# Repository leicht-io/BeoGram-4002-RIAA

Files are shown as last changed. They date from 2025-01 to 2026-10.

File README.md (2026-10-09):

# BeoGram 4002 RIAA Preamp





An open-source RIAA phono preamplifier board for the Bang & Olufsen **BeoGram 4002 / 4004** turntable, designed in KiCad.

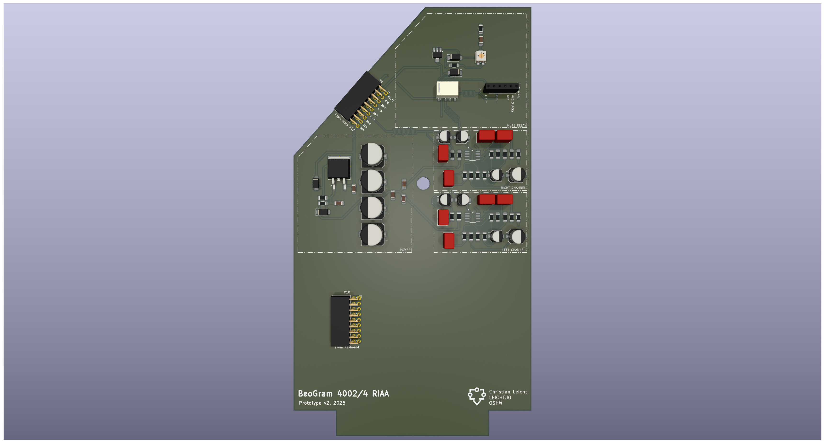
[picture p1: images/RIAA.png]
PCB render


| | |
|---|---|
| **Status** | Prototype v2 (SMD) – manufactured and tested working |
| **Tool** | KiCad 10 (files are readable by KiCad 9) |
| **Board** | 2-layer, 1.6 mm, ~112 × 202 mm |
| **Hardware licence** | [CERN-OHL-S v2](./LICENSE) |
| **Docs licence** | [CC BY-SA 4.0](./LICENSE-DOCS) |

> This project is community driven. Build reports, measurements and design improvements are very welcome – see [CONTRIBUTING.md](./CONTRIBUTING.md).
> Questions and build help: [Discussions](https://github.com/leicht-io/BeoGram-4002-RIAA/discussions).

---

## Contents

- [Technical overview](#technical-overview)
- [Connectors](#connectors)
- [Getting the fabrication files](#getting-the-fabrication-files)
- [Building one](#building-one)
- [Known issues and roadmap](#known-issues-and-roadmap)
- [Repository layout](#repository-layout)
- [Contributing](#contributing)
- [Safety and disclaimer](#safety-and-disclaimer)
- [License](#license)

---

## Technical overview

A dual-stage active/passive RIAA equalizer per channel, based on the classic LM833 application topology but using the **OPA2134** for lower distortion. Full details are in [docs/design-notes.md](./docs/design-notes.md).

- **Stage 1 (U5A / U6A):** non-inverting gain stage that sets the 3180 µs / 318 µs part of the RIAA curve.
- **75 µs network:** passive RC between the stages.
- **Stage 2 (U5B / U6B):** flat gain of about 3.15×.
- **Gain:** about 34 dB at 1 kHz (calculated, not yet measured).
- **Power:** an LM317 makes about 24.6 V from the turntable's 30 V rail. The op-amps run from this single supply, biased at half the supply.
- **Mute relay:** an Omron G6K-2 shorts both outputs to ground until the turntable's `RELAY ON` signal has been present for a while. The delay is set with RV1, and the board mutes instantly when the signal drops.

## Connectors

**P8 – From main PCB** (2×9, 2.54 mm)

| Pin | Signal |
|---|---|
| 1, 2 | RELAY ON |
| 3, 4, 5, 6 | GND |
| 7, 8 | L IN (pickup) |
| 9, 10 | GND |
| 11, 12 | R IN (pickup) |
| 13, 14 | GND |
| 15, 16 | 21 V (relay supply) |
| 17, 18 | 30 V (preamp supply) |

**P10 – From Keyboard** (2×9, 2.54 mm). Power only; the other pins are not connected.

| Pin | Signal |
|---|---|
| 3, 4 | 30 V |
| 11, 12 | 21 V |
| 13, 14 | GND |

**P9 – Output** (1×6, 2.54 mm)

| Pin | Signal |
|---|---|
| 1 | L OUT |
| 3 | R OUT |
| 2, 4, 5, 6 | GND |

## Getting the fabrication files

Gerbers and other fabrication files are **not committed** to the repository. CI generates them from the KiCad sources on every push, so they always match the design:

- **Releases:** every tagged version (`v*`) has a [GitHub release](https://github.com/leicht-io/BeoGram-4002-RIAA/releases) with the gerber zip, a schematic PDF, the BOMs, the pick-and-place file and renders.
- **Latest `main` / any PR:** open the latest [KiCad workflow run](https://github.com/leicht-io/BeoGram-4002-RIAA/actions/workflows/kicad.yml) and download the `fabrication` artifact (you must be logged in to GitHub).
- **Locally:** in KiCad, *File → Fabrication Outputs*, or run the `kicad-cli` commands from [`.github/workflows/kicad.yml`](./.github/workflows/kicad.yml).

The gerbers of the first (v1) prototype are no longer in the tree but remain in the git history.

The CI produces two BOMs:

| File | Contents |
|---|---|
| `RIAA-bom-full.csv` | Every part. The `Assembly` column says whether a part is assembled by JLCPCB or soldered by hand. |
| `RIAA-bom-jlcpcb.csv` + `RIAA-cpl-jlcpcb.csv` | Upload-ready files for JLCPCB SMT assembly. |

## Building one

1. Order the board with SMT assembly using the gerber zip, `RIAA-bom-jlcpcb.csv` and `RIAA-cpl-jlcpcb.csv`. Check the part rotations in JLCPCB's preview before confirming.
2. Hand-solder the parts marked `Hand` in `RIAA-bom-full.csv`: the film capacitors C101–C105 and C201–C205, and C103/C203.
3. Set RV1 for the unmute delay you want.
4. Install it in the turntable. *An illustrated installation guide is still missing – contributions are very welcome.*

Please post a **Build report** issue when you have built one, whether it worked or not.

## Known issues and roadmap

- [ ] **Input load is ~23.5 kΩ, not 47 kΩ.** The cartridge sees the two 47 k bias resistors in parallel. B&O MMC cartridges are specified for 47 kΩ.
- [ ] **All grounds are merged into a single GND net** (chassis, main board, pickup and output). Look at this first if hum shows up.
- [ ] **C104 / C204 (2 µF film) have no part number.**
- [ ] **ERC is not clean:** unused pins need no-connect flags and the supply nets need PWR_FLAGs.
- [ ] **No measurements yet:** RIAA deviation, noise and THD are still missing.
- [ ] **No installation guide or photos yet.**

## Repository layout

```
RIAA.kicad_pro / .kicad_sch / .kicad_pcb   KiCad project
parts/                                     Project-local footprints (OPA2134 D8)
3d-parts/                                  STL files for the 3D-printed board guides
docs/                                      Design notes
images/                                    Renders and photos
scripts/make_bom.py                        Builds the full and JLCPCB BOMs (used by CI)
.github/                                   CI workflow, issue and PR templates
```

## Contributing

See [CONTRIBUTING.md](./CONTRIBUTING.md). In short: open an issue or discussion first for design changes, keep each PR focused, and include screenshots of what you changed in the schematic or PCB.

## Safety and disclaimer

This board connects to the turntable's internal 30 V supply. Vintage equipment can be damaged by wiring mistakes. Everything here is provided **as is, without any warranty** (see the licence), and you build and install it at your own risk.

Bang & Olufsen, BeoGram and related names are trademarks of their owners. This project is not affiliated with or endorsed by Bang & Olufsen.

## License

- **Hardware design files** (KiCad, STL): [CERN Open Hardware Licence v2 – Strongly Reciprocal](./LICENSE) (CERN-OHL-S-2.0)
- **Documentation and images:** [Creative Commons Attribution-ShareAlike 4.0](./LICENSE-DOCS) (CC-BY-SA-4.0)
- **Scripts** (`scripts/`): GPL-3.0-or-later

## Author

Christian Leicht – [leicht.io](https://github.com/leicht-io)

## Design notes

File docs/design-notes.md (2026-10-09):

# Design notes

Theory of operation for the BeoGram 4002 RIAA board. References are for the left channel (1xx). The right channel is the same with 2xx references. All figures are calculated from the schematic values and have **not been measured yet**. Measurements are very welcome.

## Signal path

```
P8 L IN ─ C101 100p ─┬─ C106 10µ ─► U5A (stage 1: 3180/318 µs) ─► R107/R108/C105 (75 µs) ─ C104 2µ ─► U5B (flat ×3.15) ─ C107 10µ ─► K1 (mute) ─► P9 L OUT
                     │              bias: R102/R103 47k/47k to ½ supply
```

### Input

- C101 (100 pF) to ground sets the cartridge capacitive load. Cable capacitance adds to this.
- C106 (10 µF) is the AC coupling cap. The + input is biased at half the supply by R102/R103 (47 k / 47 k).
- **Resistive load:** R102 ∥ R103 ≈ **23.5 kΩ**. The usual moving-magnet / moving-iron load is 47 kΩ, so this is an open point (see the README's known issues).
- **Input high-pass corner:** 10 µF with 23.5 kΩ gives ≈ 0.7 Hz.

### Stage 1 – U5A (3180 µs / 318 µs)

Non-inverting amplifier with feedback Z = R106 + (R105 ∥ C102) to an AC ground through R104 + C103.

| Parameter | Formula | Value | RIAA target |
|---|---|---|---|
| Pole (bass turnover) | R105 · C102 = 80.6 k · 39 n | 3143 µs | 3180 µs |
| Zero | R105·C102 · (R104+R106)/(R104+R105+R106) | ≈ 314 µs | 318 µs |
| Mid-band gain | 1 + R106/R104 | ≈ 17.9 (25 dB) | – |
| LF gain (below 50 Hz) | 1 + (R105+R106)/R104 | ≈ 179 (45 dB) | – |
| DC gain | C103 blocks DC | 1 | – |
| LF corner | R104 · C103 = 499 · 200 µ | ≈ 1.6 Hz | – |

### 75 µs network

- R107 (2.37 k) in series, R108 (54.9 k) to ground, then C105 (33 nF) to ground at the stage 2 input. C104 (2 µF) couples the signal across, since stage 2 has its own half-supply bias (R111/R112).
- **Time constant:** (R107 ∥ R108) · C105 = 2.27 k · 33 n = **75.0 µs**.
- **Flat-band loss:** R108 / (R107 + R108) ≈ 0.96.

### Stage 2 – U5B

- **Gain:** 1 + R109/R110 = 1 + 4.3 k / 2 k ≈ 3.15 (10 dB). C108 (10 µF) makes it unity gain at DC.
- **Output:** C107 (10 µF) couples the output to the mute relay and P9.

### Overall

- **Gain at 1 kHz:** ≈ 34 dB.
- **Output level:** a typical 5 mV/1 kHz cartridge gives ≈ 250 mV out.

## Power supply

- U7 (LM317, TO-263) regulates 30 V from the main board down to `24VDC+`:
  - Vout = 1.25 V · (1 + R19/R20) = 1.25 · (1 + 5600/300) ≈ **24.6 V**
  - Dropout headroom ≈ 5.4 V
- **Protection:** D5 protects against reverse voltage from output to input. D6 discharges the adjust-pin capacitor C30 (10 µF), which improves ripple rejection.
- **Bulk capacitance:** C1, C2, C3 and C31 (4 × 470 µF).
- **Decoupling:** C27, C28 and C32 (100 nF) at the op-amps, and C29 at the regulator input.
- **Single-supply operation:** each op-amp input is biased at about 12.3 V by a 47 k / 47 k divider. The OPA2134 is rated up to 36 V total supply.

## Mute relay

- **How it mutes:** K1 is an Omron G6K-2 (DPDT). Its normally-closed contacts (pins 3 and 6) short L OUT and R OUT to ground. When the coil is energised the contacts open and the signal passes.
- **Coil drive:** the coil runs from the 21 V rail and is switched by Q1 (NPN). D7 is the flyback diode.
- **Turn-on delay:** when `RELAY ON` (P8 pins 1–2) goes high, C33 (100 µF, in series with R21 1 k) charges through R22 (100 k) and RV1 (1 M trimmer). Q1 switches on once its base reaches about 0.6 V, so RV1 sets the unmute delay.
- **Turn-off:** when `RELAY ON` goes low, D8 pulls the base low and discharges C33. The outputs mute immediately.

## Grounding

The schematic uses several ground labels (`GND`, `GND MB`, `GND CHASSIS`, `GND L/R IN PICKUP`, `GND L/R OUT`), but they all connect to one GND net. A star ground or a separate chassis ground could be worth trying if hum turns out to be a problem. Please report hum or noise in a build report.

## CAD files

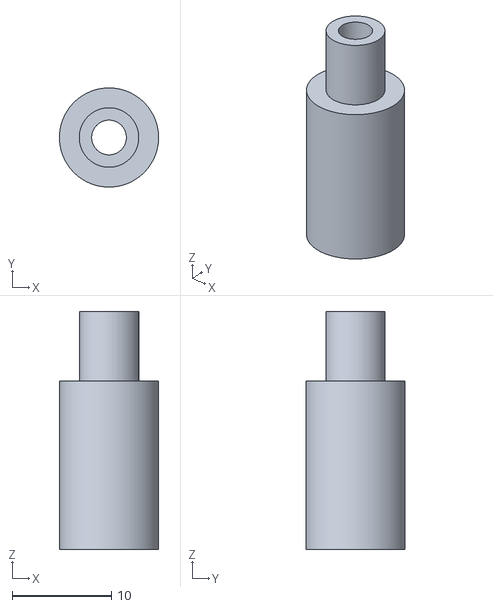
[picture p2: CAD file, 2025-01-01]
3d-parts/RIAA-guidance-bottom.stl
10.00 x 10.00 x 24.0

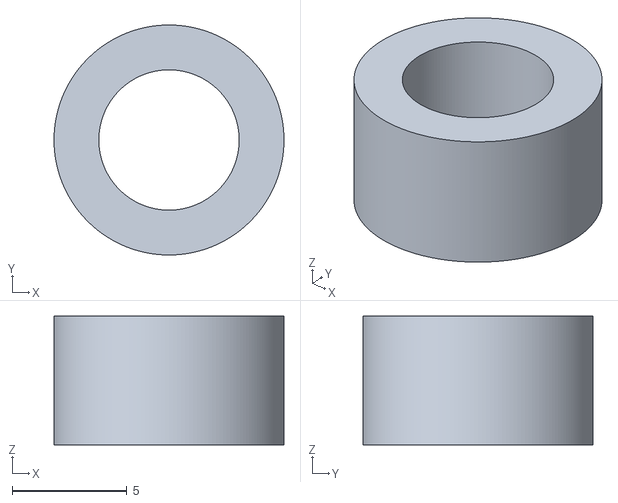
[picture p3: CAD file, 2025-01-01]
3d-parts/RIAA-guidance-top.stl
10.0 x 10.0 x 5.60

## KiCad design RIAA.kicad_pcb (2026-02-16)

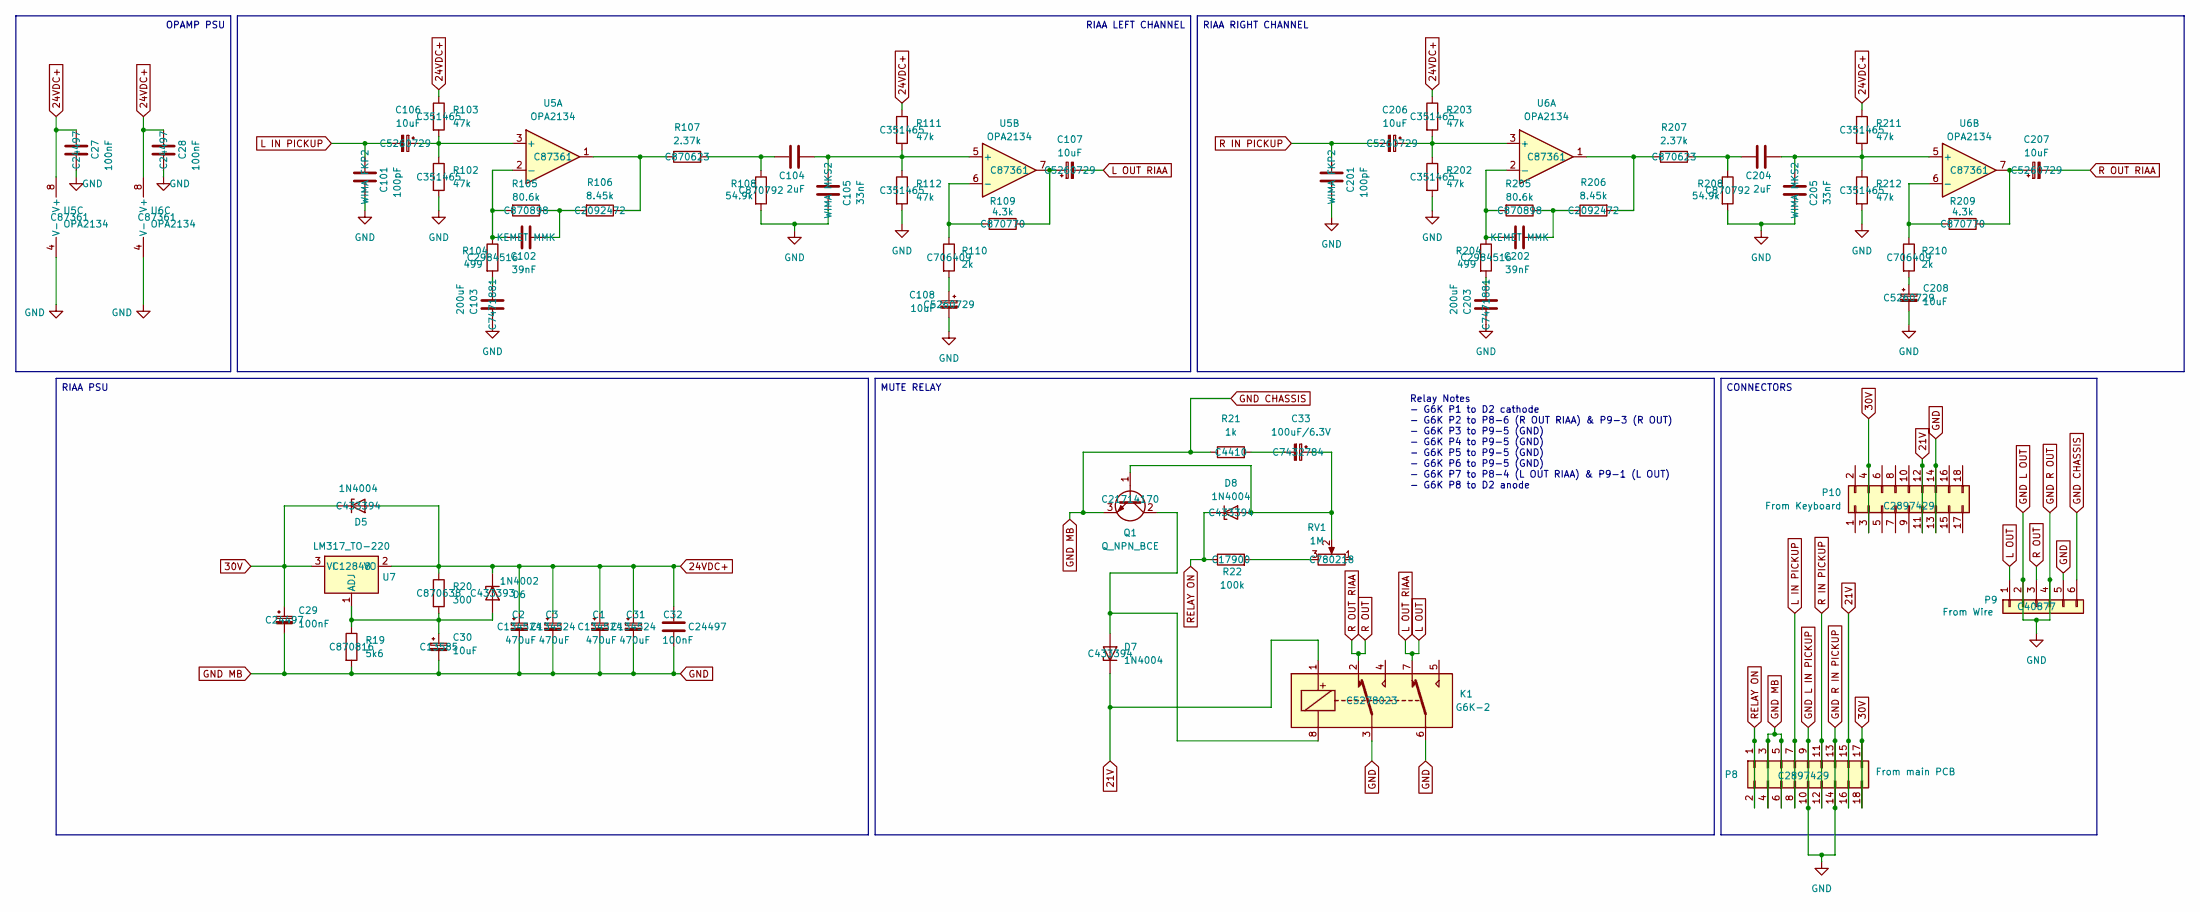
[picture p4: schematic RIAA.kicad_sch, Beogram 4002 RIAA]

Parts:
C1, C2, C3, C31: 470uF; CP_Elec_10x10.5; LCSC PN C134524
C27, C28, C29, C32: 100nF; C_1206_3216Metric_Pad1.33x1.80mm_HandSolder; LCSC PN C24497
C30: 10uF; C_1206_3216Metric_Pad1.33x1.80mm_HandSolder; LCSC PN C13585
C33: 100uF/6.3V; C_1206_3216Metric_Pad1.33x1.80mm_HandSolder; LCSC PN C7432784
C101, C201: 100pF; C_Rect_L7.2mm_W4.5mm_P5.00mm_FKS2_FKP2_MKS2_MKP2
C102, C202: 39nF; C_Rect_L7.2mm_W4.5mm_P5.00mm_FKS2_FKP2_MKS2_MKP2
C103, C203: 200uF; CP_Elec_6.3x7.7; LCSC PN C7471881
C104, C204: 2uF; C_Rect_L7.2mm_W4.5mm_P5.00mm_FKS2_FKP2_MKS2_MKP2
C105, C205: 33nF; C_Rect_L7.2mm_W4.5mm_P5.00mm_FKS2_FKP2_MKS2_MKP2
C106, C107, C108, C206, C207, C208: 10uF; CP_Elec_5x5.4; LCSC PN C5260729
D5, D7, D8: 1N4004; D_SMA; LCSC PN C433394
D6: 1N4002; D_SMA; LCSC PN C433393
K1: G6K-2; Relay_DPDT_Omron_G6K-2F-Y
P8: From main PCB; PinSocket_2x09_P2.54mm_Horizontal; LCSC PN C2897429
P9: From Wire; PinSocket_1x06_P2.54mm_Vertical; LCSC PN C40877
P10: From Keyboard; PinSocket_2x09_P2.54mm_Horizontal; LCSC PN C2897429
Q1: Q_NPN_BCE; SOT-89-3_Handsoldering; LCSC PN C21714170
R19: 5k6; R_1206_3216Metric_Pad1.30x1.75mm_HandSolder; LCSC PN C870816
R20: 300; R_1206_3216Metric_Pad1.30x1.75mm_HandSolder; LCSC PN C870638
R21: 1k; R_1206_3216Metric_Pad1.30x1.75mm_HandSolder; LCSC PN C4410
R22: 100k; R_1206_3216Metric_Pad1.30x1.75mm_HandSolder; LCSC PN C17900
R102, R103, R111, R112, R202, R203, R211, R212: 47k; R_1206_3216Metric_Pad1.30x1.75mm_HandSolder; LCSC PN C351465
R104, R204: 499; R_1206_3216Metric_Pad1.30x1.75mm_HandSolder; LCSC PN C2984516
R105, R205: 80.6k; R_1206_3216Metric_Pad1.30x1.75mm_HandSolder; LCSC PN C870898
R106, R206: 8.45k; R_1206_3216Metric_Pad1.30x1.75mm_HandSolder; LCSC PN C2092472
R107, R207: 2.37k; R_1206_3216Metric_Pad1.30x1.75mm_HandSolder; LCSC PN C870623
R108, R208: 54.9k; R_1206_3216Metric_Pad1.30x1.75mm_HandSolder; LCSC PN C870792
R109, R209: 4.3k; R_1206_3216Metric_Pad1.30x1.75mm_HandSolder; LCSC PN C870770
R110, R210: 2k; R_1206_3216Metric_Pad1.30x1.75mm_HandSolder; LCSC PN C706409
RV1: 1M; Potentiometer_Bourns_3314G_Vertical
U5, U6: OPA2134; D8; LCSC PN C87361
U7: LM317_TO-220; TO-263-2; LCSC PN C12848

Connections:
21V: D7.1 (K), K1.1, P8.15, P8.16, P10.11, P10.12
24VDC+: C1.1, C2.1, C3.1, C27.2, C28.2, C31.1, C32.2, D5.2 (A), D6.1 (K), R20.1, R103.1, R111.1, R203.1, R211.1, U5.8 (V+), U6.8 (V+), U7.2 (VO)
30V: C29.1, D5.1 (K), P8.17, P8.18, P10.3, P10.4, U7.3 (VI)
GND: C1.2, C2.2, C3.2, C27.1, C28.1, C29.2, C30.2, C31.2, C32.1, C101.1, C103.2, C105.1, C108.2, C201.1, C203.2, C205.1, C208.2, K1.3, K1.6, P8.3, P8.4, P8.5, P8.6, P8.9, P8.10, P8.13, P8.14, P9.2, P9.4, P9.5, P9.6, P10.13, P10.14, Q1.3 (E), R19.2, R21.1, R102.2, R108.2, R112.2, R202.2, R208.2, R212.2, U5.4 (V-), U6.4 (V-)
L IN PICKUP: C101.2, C106.2, P8.7, P8.8
L OUT: C107.2, K1.7, P9.1
unnamed: C33.2, R21.2
unnamed: C102.2, R105.1, R106.2
unnamed: C103.1, R104.2
unnamed: C104.1, R107.1, R108.1
unnamed: C107.1, R109.1, U5.7
unnamed: C108.1, R110.2
unnamed: C202.2, R205.1, R206.1
unnamed: C203.1, R204.2
unnamed: C204.1, R207.1, R208.1
unnamed: C207.1, R209.1, U6.7
unnamed: C208.1, R210.2
unnamed: C30.1, D6.2 (A), R19.1, R20.2, U7.1 (ADJ)
unnamed: D7.2 (A), K1.8, Q1.2 (C)
unnamed: C33.1, D8.2 (A), Q1.1 (B), RV1.2
unnamed: R22.2, RV1.3
unnamed: R106.1, R107.2, U5.1
unnamed: R206.2, R207.2, U6.1
unnamed: C106.1, R102.1, R103.2, U5.3 (+)
unnamed: C102.1, R104.1, R105.2, U5.2 (-)
unnamed: C104.2, C105.2, R111.2, R112.1, U5.5 (+)
unnamed: R109.2, R110.1, U5.6 (-)
unnamed: C206.1, R202.1, R203.2, U6.3 (+)
unnamed: C202.1, R204.1, R205.2, U6.2 (-)
unnamed: C204.2, C205.2, R211.2, R212.1, U6.5 (+)
unnamed: R209.2, R210.1, U6.6 (-)
R IN PICKUP: C201.2, C206.2, P8.11, P8.12
R OUT: C207.2, K1.2, P9.3
RELAY ON: D8.1 (K), P8.1, P8.2, R22.1

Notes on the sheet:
Relay Notes - G6K P1 to D2 cathode - G6K P2 to P8-6 (R OUT RIAA) & P9-3 (R OUT) - G6K P3 to P9-5 (GND) - G6K P4 to P9-5 (GND) - G6K P5 to P9-5 (GND) - G6K P6 to P9-5 (GND) - G6K P7 to P8-4 (L OUT RIAA) & P9-1 (L OUT) - G6K P8 to D2 anode
RIAA RIGHT CHANNEL
RIAA LEFT CHANNEL
OPAMP PSU
CONNECTORS
RIAA PSU
MUTE RELAY

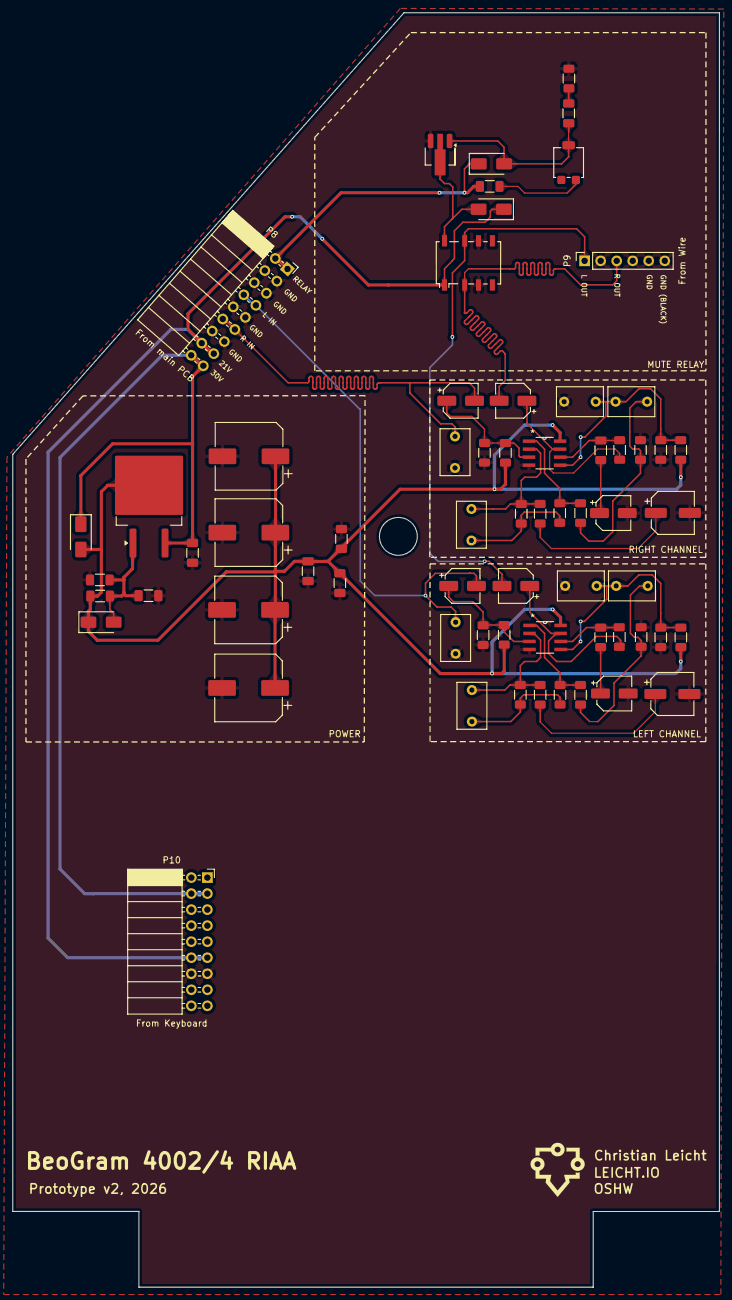
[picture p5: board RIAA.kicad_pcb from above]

Board: 2 copper layers, 112.0 x 202.0 mm, 65 parts (0 on the bottom side), 34 nets.

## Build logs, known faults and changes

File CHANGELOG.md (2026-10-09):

# Changelog

Hardware revisions of the BeoGram 4002 RIAA board.

## [Unreleased]

- Fixed misspelled `LCSC PN` fields on K1 and RV1 so they appear in the JLCPCB BOM.
- Repository: switched the licence to CERN-OHL-S v2 (hardware) / CC BY-SA 4.0 (docs). Fabrication files are now built by CI and attached to releases instead of being committed.

## Prototype v2 – SMD (2026)

- Converted to SMD with JLCPCB assembly. The film capacitors are still through-hole and soldered by hand.
- LM317 regulator (30 V → ~24.6 V) on the board.
- Mute relay (Omron G6K-2) with an adjustable unmute delay.
- Manufactured and tested working.

## Prototype v1 (2025)

- First through-hole prototype.

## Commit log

2024-04-18 feat: initial release.
    [RIAA.kicad_pcb, RIAA.kicad_sch]
2024-04-25 feat: updated schematics.
    [RIAA.kicad_pcb, RIAA.kicad_sch]
2025-01-01 Added 3d guidance parts
    [RIAA-guidance-bottom.stl, RIAA-guidance-top.stl]
2025-01-01 feat: reversed D1.
    [RIAA-guidance-bottom.stl, RIAA-guidance-top.stl, RIAA.kicad_pcb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]
2025-01-01 feat: Updated PSU resistor values.
    [RIAA.kicad_pcb, RIAA.kicad_sch]
2025-01-02 feat: Updated PCB.
    [RIAA.kicad_pcb, RIAA.kicad_sch]
2025-01-04 feat: Updated orientation of D1.
    [RIAA.kicad_pcb, RIAA.kicad_sch]
2025-01-05 feat: added classic linear power supply
    [RIAA.kicad_pcb, RIAA.kicad_sch]
2025-01-06 WIP: Committing the changes from yesterday.
    [RIAA.kicad_pcb, RIAA.kicad_sch]
2025-01-06 WIP: Added gerber files.
    [BOM-RIAA.csv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]
2025-01-07 WIP: Started on 3v3 voltage regulator for esp32.
    [RIAA.kicad_sch]
2026-01-26 WIP: Working on SMD version.
    [RIAA.kicad_pcb, RIAA.kicad_sch]
2026-01-27 WIP: Working on SMD.
    [RIAA.kicad_pcb, RIAA.kicad_sch]
2026-01-27 WIP: Added Bourne 3315J footprint.
    [3314J-1-105E.step]
2026-01-27 WIP: Finishing up SMD version.
    [RIAA.kicad_pcb, RIAA.kicad_sch]
2026-01-28 WIP: Adding LSCS PNs.
    [RIAA.kicad_pcb, RIAA.kicad_sch]
2026-10-09 Set up repository for open-source community development
    - Relicense: CERN-OHL-S v2 for hardware, CC BY-SA 4.0 for docs,
    GPL-3.0-or-later for scripts.
    - Stop tracking generated and per-user files (production zips, backups,
    v1 gerbers, .kicad_prl, .wbk); extend .gitignore accordingly.
    - Remove unused 3314J trimmer library.
    - Fix misspelled "LSCS PN" / " PN" fields so K1 and RV1 appear in the BOM.
    - Add KiCad CI: DRC (blocking), ERC (report-only), schematic PDF, gerbers,
    full + JLCPCB BOM/CPL, renders, and draft releases on v* tags.
    - Add scripts/make_bom.py to include hand-soldered parts in the full BOM.
    - Rewrite README (pinouts, build steps, known issues), add design notes,
    CONTRIBUT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
    [3314J-1-105E.step, BOM-RIAA.csv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]
2026-10-09 Drop gerber generation from CI, releases and docs
2026-10-09 Remove remaining mentions of gerbers from docs
2026-10-09 Build gerbers in CI again
    Reverts the gerber removal: CI builds the gerber zip and attaches it to
    releases, and the docs list it among the outputs.
2026-10-22 Add manufacturer part numbers and PCBWay turnkey BOM
    Every part now carries Manufacturer and MPN fields in the schematic and
    on the board, next to the existing LCSC numbers. The film capacitors get
    full WIMA part numbers instead of series names and Mouser links.
    make_bom.py additionally writes RIAA-bom-pcbway.csv (all parts by MPN,
    with LCSC as distributor PN) and RIAA-cpl-pcbway.csv (SMD parts only);
    the JLCPCB files are unchanged. CI attaches both to releases.
    The board's zones and teardrops are rebuilt after the output meanders
    were removed, which also clears a stale zone clearance violation on
    R OUT. README render, docs and changelog updated.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
2026-10-22 Ceramic capacitors, 38 dB gain, output resistors and 4004 checks
    - C1, C34/C35 and C107/C207 are now 1206 ceramics (C34/C35 22 uF to
    allow for DC-bias loss); the six remaining electrolytics are where a
    ceramic would be microphonic or add distortion (see design notes).
    - R109/R209 4.3k -> 7.5k (RESI PTFR1206B7K50P9, C351451): gain about
    38 dB, to suit B&O's low-output MMC cartridges.
    - New R113/R213 (100 R, C17901) between each op-amp output and its
    output capacitor, outside the feedback loop.
    - P9 pins 2/4 are no-connects, matching the original P9 pin layout, so
    a 4004 harness no longer shorts the Beomaster 2400 remote lines; a
    ground via keeps K1's mute contact on the plane.
    - C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
2026-10-22 Schematic tidy-up: ERC without warnings, relay part named
    - D5-D8 use the plain diode symbol (were drawn as Zeners; same pins).
    - Duplicate net names removed: GND MB and GND CHASSIS labels are now
    GND, L/R OUT RIAA are now L/R OUT. Connectivity is unchanged
    (netlist compared before and after).
    - RV1's embedded symbol matches the library.
    - K1 value reads G6K-2F-Y DC24, the 24 V part already on the BOM.
    - POWER silkscreen outline and label moved 0.7 mm left, off R24's pad.
    - Design notes: relay contacts described correctly (commons 3/6 on GND,
    normally-closed 2/7 on the outputs); README names the 24 V relay.
    ERC: 0 errors, 0 warnings. DRC: 0 errors, 0 unconnected, 0 parity
    issues; the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
